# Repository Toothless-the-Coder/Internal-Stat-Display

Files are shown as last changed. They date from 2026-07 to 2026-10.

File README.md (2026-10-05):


# Pi Pico Computer Stats Display

## Why I Built This

I wanted a **physical, always-on display** of my system stats without using up screen space or keeping another app open. Most monitoring tools are digital dashboards on your monitor—I wanted something tangible in my computer. Plus, there's something satisfying about watching real hardware respond to your system's performance in real-time.

## What It Does

This system continuously monitors your Linux computer and displays key performance metrics on three physical LCD screens

### Component Wiring Diagram



## Assenbly instructions
1. Place the screens into their circular cutouts on the front
2. Slide in the plate behind the screens to keep them from falling back
3. Upload the code onto the raspberry pi                                                                 
4. Plug the screens into the raspberry Pi using jumper cables following the wiring diagram just up there 
5. Route the cable from the usb headers through the cutout in the backplate and plug it into the raspberry pi's usb port
6. Screw or glue the raspberry pi's securing plate on (I recommend screws)
7. Screw on the back and top plate and connect it to the usb headers
8. Click it into place in your pc case (Designed specifically for mine so you'll have to edit the external case to make it fit your pc)
9. Enjoy the beautiful displays!

## BOM

| Component | Price | Source | Link |
|---|---|---|---|
| Raspberry Pi Pico | $6 | digikey | https://www.digikey.com/en/products/detail/raspberry-pi/SC0918/16608263 |
| 6mm m2x.4 screws | $0.65 | digikey | https://www.digikey.com/en/products/detail/essentra-components/50M020040G004/11638015 |
| 3x LCD 1602 + I2C backpack | $14.99 each | WaveShare | https://www.waveshare.com/1.28inch-lcd-module.htm |
| Micro USB cable | $8.43 | newegg | https://www.newegg.com/p/27U-00H1-000P4?Item=9SIAERNM1X0850 |
| Digikey Shipping | $8.49 | FedEx Ground | |
| NewEgg Shipping | Free | | |
| WaveShare Shipping | $10.00 | | |
| Print Legion | $5.00 | | |
| **Total** | **~$83.54** | | |






I do not have a hackatime project for this, the connectors aren't jst, they're standard 2.54mm shrouded pin sockets which will connect to the pi via jumper cables, I am planning to have this printed through hack club's print legion, the last reviewer said to include the costs of print legion in the bom, but I was under the impression that print legion was free.

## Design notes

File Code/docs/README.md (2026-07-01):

# Pi Pico Computer Stats Display

> A compact, always-on dashboard for monitoring your Linux system—built with hardware that costs less than a coffee.

## 🎯 Why I Built This

I wanted a **physical, always-on display** of my system stats without using screen real estate or keeping another app open. Most monitoring tools are digital dashboards on your monitor—I wanted something tangible on my desk. Plus, there's something satisfying about watching real hardware respond to your system's performance in real-time.

This project combines:
- **Raspberry Pi Pico** (~$5)—a tiny, powerful microcontroller
- **3 LCD displays**—each showing different stats
- **Your Linux computer**—streaming live data

The result? A **device that sits on your desk and shows your system's heartbeat** in real-time.

## 📊 What It Does

This system continuously monitors your Linux computer and displays key performance metrics on three physical LCD screens:

```
┌─────────────────┐    ┌─────────────────┐    ┌─────────────────┐
│  SCREEN 1       │    │  SCREEN 2       │    │  SCREEN 3       │
│                 │    │                 │    │                 │
│  CPU: 45.2%     │    │  RAM: 62.3%     │    │  GPU: 78%       │
│  Temp: 52.5°C   │    │  Net: 1.5MB/s   │    │  OK             │
└─────────────────┘    └─────────────────┘    └─────────────────┘
```

**Monitored Stats:**
- CPU usage percentage
- RAM usage percentage
- GPU usage percentage
- CPU temperature
- Network speed

All updating in real-time, wirelessly communicating over USB.

## 🔧 How It Fits Together

### The Big Picture

```
┌──────────────────────────────────────────────────────────────┐
│                      YOUR LINUX PC                           │
│                                                              │
│  ┌─────────────────────────────────────────────────────┐   │
│  │ stat_sender.py (Python script)                      │   │
│  │ • Reads CPU, RAM, GPU, Temperature, Network data   │   │
│  │ • Packages it as JSON                              │   │
│  │ • Sends over USB serial connection                 │   │
│  └────────────────────────────┬────────────────────────┘   │
│                               │                             │
│                          USB Port                           │
│                          (Serial)                           │
│                               │                             │
└───────────────────────────────┼─────────────────────────────┘
                                │
                        [USB Cable]
                                │
┌───────────────────────────────┼─────────────────────────────┐
│                               │                             │
│  ┌────────────────────────────▼───────────────────────┐    │
│  │         RASPBERRY PI PICO (Microcontroller)        │    │
│  │                                                    │    │
│  │  • Receives JSON data via USB serial              │    │
│  │  • Decodes and parses stats                       │    │
│  │  • Manages 3 I2C LCD displays in parallel         │    │
│  └────────────────┬──────────────────────────────────┘    │
│                   │                                        │
│        I2C Bus (2 wires: SDA + SCL)                       │
│                   │                                        │
│    ┌──────────────┼──────────────┐                         │
│    │              │              │                         │
│  ┌─┴──┐         ┌─┴──┐         ┌─┴──┐                      │
│  │LCD1│         │LCD2│         │LCD3│                      │
│  │0x27│         │0x26│         │0x25│                      │
│  └────┘         └────┘         └────┘                      │
│                                                            │
└────────────────────────────────────────────────────────────┘
```

### Hardware Connections

#### **I2C Bus (Data Connection)**

All three LCDs connect to the **same I2C bus** on the Pico using just 2 wires:

```
Raspberry Pi Pico        All 3 LCD Displays
─────────────────        ──────────────────

GPIO0 (SDA) ─────┬──────► LCD1 SDA
            │   LCD2 SDA
            │   LCD3 SDA
            └─────────────────────
                 (all connected)

GPIO1 (SCL) ─────┬──────► LCD1 SCL
            │   LCD2 SCL
            │   LCD3 SCL
            └─────────────────────
                 (all connected)

VBUS (5V) ────┬──────► LCD1 VCC
          │   LCD2 VCC
          │   LCD3 VCC
          └─────────────────────

GND ──────┬──────► LCD1 GND
          │   LCD2 GND
          │   LCD3 GND
          └─────────────────────
```

**Why I2C?** It's designed for exactly this—multiple devices on the same bus, each with a unique address. Perfect for daisy-chaining displays.

#### **USB Connection (Power + Data)**

```
Raspberry Pi Pico              Your Linux Computer
─────────────────              ───────────────────

Micro USB Port ════════════════ USB Port
  - Power (5V)
  - Data (RX/TX serial)
```

The USB provides:
- **Power** to run the Pico and LCDs
- **Data** for serial communication (115200 baud)

### Component Wiring Diagram

```
                    Raspberry Pi Pico
                    
                    USB [to computer]
                     ▲
                     │
        ┌────────────┼────────────┐
        │            │            │
      VBUS          GND     GPIO0/GPIO1
        │            │        (SDA/SCL)
        │            │           │
        ├────────────┼───────────┬┤
        │            │           ││
     ┌──┴──┐     ┌───┴──┐   ┌───┴┴──┐
     │     │     │      │   │       │
    LCD1  LCD2  LCD3   GND  Pull-up  (optional)
   0x27  0x26  0x25    All  4.7kΩ   Resistors
     │     │     │      │   │
    VCC   VCC   VCC    GND  
     │     │     │      │
    (All connected in parallel on same 4 wires)
```

## 📦 The Three Screens

Each LCD is independently addressable on the I2C bus:

| Screen | Address | Content | Purpose |
|---|---|---|---|
| **LCD1** | `0x27` | CPU Usage + Temperature | Processor monitoring |
| **LCD2** | `0x26` | RAM Usage + Network Speed | Memory & connectivity |
| **LCD3** | `0x25` | GPU Usage + Status | Graphics performance |

## 🎛️ System Features
- Real-time system stat monitoring (CPU, RAM, GPU, Temperature, Network)
- Display on three separate 16x2 character LCD screens
- USB serial communication from host computer
- JSON-based protocol for easy extension
- Low power consumption (~500mA)
- Auto-detection of connected displays

## 🛒 What You Need

| Component | Price | Source |
|---|---|---|
| Raspberry Pi Pico | $5 | raspberrypi.com |
| 3x LCD 1602 + I2C backpack | $3-5 each | Amazon/AliExpress |
| Micro USB cable | $2-5 | Any electronics store |
| Breadboard & jumper wires | $5-10 | Electronics kit |
| **Total** | **~$30-40** | Budget-friendly! |

### Raspberry Pi Pico Specs
- **Microcontroller:** RP2040
- **RAM:** 264KB
- **Flash:** 2MB
- **I2C Support:** 2 I2C buses
- **UART Support:** 2 serial ports
- **Size:** 21x51mm (tiny!)

### LCD Displays
- **Type:** 1602 (16 characters × 2 rows)
- **Connection:** I2C via PCF8574 backpack
- **Power:** 5V
- **Current:** ~80-150mA per display (with backlight)

## 🏗️ Software Architecture

### On the Pico (MicroPython)

```
main.py ─────────────────────────────────────
    │
    ├─► config.py ◄─ [Configuration: pins, addresses, update rate]
    │
    ├─► serial_handler.py ◄─ [Receives JSON from Linux]
    │        │
    │        └─► Parses incoming stats
    │
    ├─► display_manager.py ◄─ [Manages 3 LCD screens]
    │        │
    │        └─► Updates stats on displays
    │
    └─► lcd_i2c.py ◄─ [I2C LCD driver]
             │
             └─► Controls each display
```

**Key Files:**
- `main.py` — Runs the main loop
- `config.py` — I2C pins, LCD addresses, update speed
- `serial_handler.py` — Reads JSON from USB
- `display_manager.py` — Logic for what shows on each screen
- `lcd_i2c.py` — Low-level LCD communication

### On Your Linux Computer (Python 3)

```
stat_sender.py ────────────────────────────────
    │
    ├─► Read system stats (psutil library)
    │    ├─ CPU usage
    │    ├─ RAM usage
    │    ├─ GPU usage
    │    ├─ Temperature
    │    └─ Network speed
    │
    ├─► Format as JSON
    │
    └─► Send via USB serial
             │
             └─► To Pico
```

**Key File:**
- `stat_sender.py` — Gathers stats and sends to Pico

## ⚡ Quick Start (15 Minutes)

**Start here:** See [QUICKSTART.md](../QUICKSTART.md)

For detailed setup:
1. [Wiring & Hardware Setup](../docs/HARDWARE.md)
2. [Pico Firmware Installation](../QUICKSTART.md)
3. [Linux Sender Setup](../linux_sender/SETUP.md)

## 🚀 Running It

### Start the Linux Sender

```bash
cd linux_sender
python3 stat_sender.py
```

**Options:**
```bash
python3 stat_sender.py --port /dev/ttyACM0  # Specify port
python3 stat_sender.py --interval 2.0       # Update every 2 seconds
python3 stat_sender.py --baud 115200        # Custom baud rate
```

**That's it!** Stats should start appearing on your displays within seconds.

### Run as a Background Service

To have it start automatically on boot:

```bash
# See linux_sender/SETUP.md for systemd service installation
```

## 🖥️ What You'll See

The three LCD displays show:

```
LCD 1 (0x27)              LCD 2 (0x26)              LCD 3 (0x25)
┌──────────────────┐      ┌──────────────────┐      ┌──────────────────┐
│ CPU: 45.2%       │      │ RAM: 62.3%       │      │ GPU: 78%         │
│ Temp: 52.5C      │      │ Net: 1.5MB/s     │      │ Stat Display OK  │
└──────────────────┘      └──────────────────┘      └──────────────────┘
```

Each display updates **1x per second** (configurable).

## 🔧 Troubleshooting

| Problem | Solution |
|---|---|
| **No displays showing** | Check I2C wiring: SDA (GPIO0), SCL (GPIO1), power, ground |
| **Only some displays work** | Run I2C scan to find addresses, update `config.py` |
| **Serial connection fails** | Check port: `ls /dev/ttyACM*` or use `--port` option |
| **Stats not updating** | Verify `stat_sender.py` is running |
| **Garbled text on displays** | Ensure 5V power to LCDs, check wiring |

**For detailed troubleshooting:** See [HARDWARE.md](../docs/HARDWARE.md)

## Performance Notes

- I2C clock: 400kHz (standard)
- Serial baud: 115200
- Update frequency: 1 second (adjustable)
- Pico CPU usage: <5% typical

## 💬 How Devices Communicate

The Pico and Linux computer exchange information in **JSON format** over USB serial.

### Message Format (Linux → Pico)

```json
{
  "cpu": 45.2,
  "ram": 62.3,
  "gpu": 78,
  "temp": 52.5,
  "network": "1.5MB/s"
}
```

Each message is one line, sent **1x per second**.

**For the full protocol spec:** See [PROTOCOL.md](../docs/PROTOCOL.md)

## ⚙️ Performance Specs

- **I2C Speed:** 400kHz (standard)
- **Serial Baud:** 115200
- **Update Frequency:** 1 second (adjustable)
- **Pico CPU Usage:** <5%
- **Power Consumption:** 400-600mA total

## 📚 Documentation

- **[QUICKSTART.md](../QUICKSTART.md)** — Get running in 15 minutes
- **[HARDWARE.md](../docs/HARDWARE.md)** — Detailed wiring and troubleshooting
- **[PROTOCOL.md](../docs/PROTOCOL.md)** — Communication format and extending
- **[SETUP.md](../linux_sender/SETUP.md)** — Linux sender installation

## 🛠️ Customization

### Change Update Frequency
Edit `pico_firmware/config.py`:
```python
UPDATE_INTERVAL = 500  # Update every 500ms instead of 1000ms
```

### Adjust What's Displayed
Edit `pico_firmware/display_manager.py`:
```python
def _display_screen_0(self, lcd):
    # Customize Screen 1 here
    cpu_str = f"CPU: {self.stats['cpu']}%"
    custom_str = f"Your stat here"
    lcd.write_line(0, cpu_str)
    lcd.write_line(1, custom_str)
```

### Add New Statistics
1. Update Linux sender to collect the stat
2. Add the field to the JSON message
3. Update Pico's `display_manager.py` to show it

See [PROTOCOL.md](../docs/PROTOCOL.md) for a detailed example.

## 🚀 Future Ideas

- [ ] OLED display support for better visuals
- [ ] Graph mode (bar graphs on LCD)
- [ ] SD card logging
- [ ] Pi Pico W (wireless Ethernet instead of USB)
- [ ] Custom character support for better icons
- [ ] Multi-computer monitoring

## 📝 License

Open source — modify and share freely!

## 🤝 Support

1. **Can't get it working?** Start with [QUICKSTART.md](../QUICKSTART.md)
2. **Hardware issues?** Check [HARDWARE.md](../docs/HARDWARE.md)
3. **Need more info?** See full documentation in `/docs`

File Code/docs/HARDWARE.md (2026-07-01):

# Hardware Setup Guide

## Pinout Reference

### Raspberry Pi Pico

```
        USB
       ╔═══╗
     1 ║o o║ 40
    20 ╚═══╝ 21

GPIO Pins (numbers are GPIO numbers):
Top Row (L to R):    1(GP0), 2(GP1), 4(GP2), 5(GP3), 7(GP4), 8(GP5),
                     10(GP6), 11(GP7), 13(GP8), 14(GP9), 16(GP10), 17(GP11),
                     19(GP12), 20(GP13), 22(GP14), 24(GP15), 25(GP16), 26(GP17),
                     27(GP18), 28(GP19), 30(GP20), 31(GP21), 32(GP22)

Bottom Row (L to R):  GND, GP23, GND, GND, GND, VSYS, GND, 3V3-OUT, 3V3-EN
```

### I2C LCD 1602 Pinout (with PCF8574 Backpack)

```
Pin 1: VSS (GND)
Pin 2: VDD (5V)
Pin 3: V0 (Contrast) - Connected to backpack
Pin 4: RS (Register Select) - PCF8574 Pin 0
Pin 5: RW (Read/Write) - PCF8574 Pin 1 (GND on backpack)
Pin 6: EN (Enable) - PCF8574 Pin 2
Pin 7-10: D4-D7 (Data pins) - PCF8574 Pins 4-7
Pin 11-14: D0-D3 (not used in 4-bit mode)
Pin 15: A (Backlight +) - PCF8574 Pin 3 through resistor
Pin 16: K (Backlight -) - GND
```

## Wiring Diagram

### Single I2C LCD to Pico

```
LCD I2C Backpack          Raspberry Pi Pico
─────────────────         ──────────────────
VCC (5V)   ────────────── VBUS (Pin 40)
GND        ────────────── GND (Pin 38, 43)
SDA        ────────────── GPIO0 (Pin 1)
SCL        ────────────── GPIO1 (Pin 2)
```

### Three I2C LCDs to Pico (Parallel I2C Bus)

```
                     ┌─────────┐
                     │ Pico    │
                     │ GPIO0   │
                     │ (SDA)   │
                     │ GPIO1   │
                     │ (SCL)   │
                     │ VBUS    │
                     │ GND     │
                     └────┬────┘
                          │
        ┌─────────────────┼─────────────────┐
        │                 │                 │
    ┌───┴────┐        ┌───┴────┐       ┌───┴────┐
    │LCD1    │        │LCD2    │       │LCD3    │
    │0x27    │        │0x26    │       │0x25    │
    └────────┘        └────────┘       └────────┘
```

All three LCDs share the same SDA and SCL lines (I2C is a shared bus).
Each LCD has a different I2C address (set via A0, A1, A2 pins on backpack).

## I2C Address Selection

PCF8574 I2C addresses are determined by A0, A1, A2 pins:

| A2 | A1 | A0 | Address |
|----|----|----|---|
| 0  | 0  | 0  | 0x20 |
| 0  | 0  | 1  | 0x21 |
| 0  | 1  | 0  | 0x22 |
| 0  | 1  | 1  | 0x23 |
| 1  | 0  | 0  | 0x24 |
| 1  | 0  | 1  | 0x25 |
| 1  | 1  | 0  | 0x26 |
| 1  | 1  | 1  | 0x27 |

Most modules default to 0x27 (all pins pulled high).

## Component List

### Essential
- 1x Raspberry Pi Pico (~$5)
- 3x LCD 1602 displays with I2C backpack (~$10-15 each)
- 1x Micro USB cable (for power/data)
- 1x Breadboard (for prototyping)
- Jumper wires (22 AWG)

### Recommended
- Pull-up resistors: 4.7kΩ (2x, for SDA/SCL lines)
- Small resistor: 330Ω (for LCD backlight, already included on most backpacks)
- Pi Pico debug probe (optional, for advanced debugging)

## Assembly Steps

### 1. Connect I2C Bus
Solder or connect with breadboard:
- Connect all LCD SDA pins → Pico GPIO0 (Pin 1)
- Connect all LCD SCL pins → Pico GPIO1 (Pin 2)
- Connect all LCD GND → Pico GND
- Connect all LCD VCC → Pico VBUS (5V)

### 2. Add Pull-up Resistors (if needed)
If LCDs aren't responding:
- 4.7kΩ resistor from SDA → VBUS
- 4.7kΩ resistor from SCL → VBUS

### 3. Verify I2C Addresses
Set different addresses on each LCD by connecting/leaving A0, A1, A2 pins:
- Open each display and set pins as needed
- Or program via I2C address selection

### 4. USB Connection
- Connect Pico micro USB port to Linux computer

## Power Considerations

### Power Budget
- Pico: ~120mA typical
- Each LCD (with backlight): ~80-150mA
- Total: ~500-600mA

**Note:** Most USB ports provide 500mA, so you may need a powered hub or additional power supply for all displays at full brightness.

### Reducing Power
- Reduce LCD backlight brightness (PWM on backlight pin)
- Reduce I2C clock speed (affects power consumption slightly)
- Reduce stat update frequency

## Testing the Wiring

### Test 1: Scan I2C Bus
```python
import machine
i2c = machine.I2C(0, scl=machine.Pin(1), sda=machine.Pin(0), freq=400000)
devices = i2c.scan()
print(f"Found {len(devices)} devices: {[f'0x{d:02x}' for d in devices]}")
# Should output: Found 3 devices: ['0x27', '0x26', '0x25']
```

### Test 2: Write to LCD
```python
from lcd_i2c import LCD_I2C
i2c = machine.I2C(0, scl=machine.Pin(1), sda=machine.Pin(0))
lcd = LCD_I2C(i2c, 0x27, 2, 16)
lcd.write_line(0, "Test Display")
lcd.write_line(1, "Screen 1")
```

### Test 3: Check USB Serial
```bash
# Linux
sudo dmesg | tail
# Look for "CDC ACM device" or similar
ls /dev/ttyACM*
```

## Troubleshooting Hardware

### LCDs Not Responding
1. Check power: Measure 5V on LCD VCC pin
2. Check I2C communication: Use logic analyzer or oscilloscope
3. Verify pull-up resistors if bus fails at distances > 1m

### One LCD Missing from Scan
1. Check physical connection
2. Verify A0/A1/A2 pins set correctly
3. Try swapping with known-working LCD
4. Reset LCD with power cycle

### Intermittent Display Glitches
1. Reduce I2C clock speed in code (from 400kHz to 100kHz)
2. Add 0.1µF capacitors near LCD power pins
3. Check for ground loops or long wire runs

### USB Connection Not Working
1. Try different USB port on computer
2. Try different USB cable (some are power-only)
3. Check dmesg for connection errors
4. Press BOOTSEL + Power to reset Pico

## Performance Tips

- **I2C Speed**: 400kHz is standard and reliable
- **Cable Length**: Keep I2C cables <1m for 400kHz
- **Power Supply**: Use regulated 5V, not USB hub's voltage
- **Grounding**: Good ground connections are critical for I2C reliability

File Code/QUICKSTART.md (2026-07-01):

# Quick Start Guide

Get your Pi Pico stat display running in 15 minutes.

## Prerequisites

- Raspberry Pi Pico (flashed with MicroPython)
- 3x LCD 1602 displays with I2C backpack
- Linux computer
- USB cable for Pico
- Python 3.7+ on Linux

## Step 1: Flash MicroPython to Pi Pico (5 min)

1. Download MicroPython: https://micropython.org/download/rp2-pico/
2. Hold BOOTSEL button on Pico
3. Connect USB to computer (Pico still held)
4. Release BOOTSEL
5. Copy downloaded `.uf2` file to `RPI-RP2` drive
6. Pico reboots automatically

## Step 2: Verify I2C Addresses (2 min)

Use Thonny IDE to run this code on Pico:

```python
import machine
i2c = machine.I2C(0, scl=machine.Pin(1), sda=machine.Pin(0))
print("I2C addresses found:", [hex(addr) for addr in i2c.scan()])
```

Should output something like: `['0x27', '0x26', '0x25']`

If not all three show up:
- Check wiring
- Verify LCD power connections
- See [HARDWARE.md](HARDWARE.md) troubleshooting

## Step 3: Upload Pico Firmware (3 min)

In Thonny IDE:
1. File → Open → Select each Python file from `pico_firmware/`
2. Save each to Pico (right-click file → Save to device)
3. Upload in this order:
   - `config.py`
   - `lcd_i2c.py`
   - `serial_handler.py`
   - `display_manager.py`
   - `main.py`

Pico should start running automatically after `main.py` is uploaded.

## Step 4: Setup Linux Sender (3 min)

```bash
cd linux_sender
pip install -r requirements.txt
python3 stat_sender.py
```

That's it! You should see stats updating on the displays.

## Troubleshooting

### No stats appearing on display?

1. **Check serial connection:**
   ```bash
   ls /dev/ttyACM*
   ```

2. **Check I2C connection:**
   - Run I2C scan in Thonny (Step 2)
   - All three LCDs should appear

3. **Manual port specification:**
   ```bash
   python3 stat_sender.py --port /dev/ttyACM0
   ```

4. **Check Pico output:**
   - Open Thonny serial monitor
   - Should see connection messages
   - Watch for errors

### One or more LCDs not showing data?

- Check I2C address (run scan, update `config.py`)
- Verify all are connected to same I2C bus
- Check power to each LCD

### Stats not updating?

- Verify stat_sender.py is running: `ps aux | grep stat_sender`
- Check for errors in Linux terminal
- Restart both Pico and stat_sender

## What's Next?

- **Customize stats:** Edit `display_manager.py` to show different info
- **Change refresh rate:** Edit `UPDATE_INTERVAL` in `config.py`
- **Add new metrics:** See [PROTOCOL.md](../docs/PROTOCOL.md) for extending
- **Run as service:** See [SETUP.md](SETUP.md) for systemd integration

## Important Files

| File | Purpose |
|---|---|
| `pico_firmware/main.py` | Pico entry point |
| `pico_firmware/config.py` | I2C addresses, pins, update rate |
| `linux_sender/stat_sender.py` | Sends system stats to Pico |
| `docs/README.md` | Full documentation |
| `docs/HARDWARE.md` | Wiring diagrams |
| `docs/PROTOCOL.md` | Communication format |

## Display Layout

**LCD 1 (Screen 1):**
```
CPU: 45.2%
Temp: 52.5C
```

**LCD 2 (Screen 2):**
```
RAM: 62.3%
Net: 1.5MB/s
```

**LCD 3 (Screen 3):**
```
GPU: 78%
Stat Display OK
```

## Performance

- CPU usage (Pico): <5%
- CPU usage (Linux): <2%
- Update latency: <100ms
- Power consumption: ~400-600mA

## Support

For detailed information:
- Wiring issues → See `docs/HARDWARE.md`
- Communication problems → See `docs/PROTOCOL.md`
- Installation help → See `linux_sender/SETUP.md`
- General info → See `docs/README.md`

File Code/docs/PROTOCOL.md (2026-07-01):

# Communication Protocol

## Overview

The Pi Pico and Linux computer communicate via USB serial using JSON messages. Each message is one line of JSON terminated with a newline (`\n`).

## Baud Rate & Serial Settings
- **Baud Rate**: 115200
- **Data Bits**: 8
- **Parity**: None
- **Stop Bits**: 1
- **Flow Control**: None

## Message Format

All messages are UTF-8 encoded JSON strings, one per line.

### Host → Pico: Statistics Update

**Message Type**: `stats`

```json
{
  "cpu": 45.2,
  "ram": 62.3,
  "gpu": 78,
  "temp": 52.5,
  "network": "1.5MB/s"
}
```

**Fields:**
| Field | Type | Range | Description |
|---|---|---|---|
| `cpu` | float | 0-100 | CPU usage percentage |
| `ram` | float | 0-100 | RAM usage percentage |
| `gpu` | float | 0-100 | GPU usage percentage (0 if unavailable) |
| `temp` | float | -50-120 | CPU temperature in Celsius |
| `network` | string | - | Network speed (e.g., "1.5MB/s", "250KB/s") |

**Frequency**: Recommended 1-2 times per second for smooth display updates

### Pico → Host: Status Acknowledgment (Optional)

**Message Type**: `status`

```json
{"status": "ok"}
```

Sent by Pico after successfully parsing a stats message (optional feature, not implemented by default).

## Protocol Examples

### Valid Statistics Messages

```json
{"cpu": 0, "ram": 0, "gpu": 0, "temp": 20, "network": "0KB/s"}

{"cpu": 100, "ram": 95.5, "gpu": 87.2, "temp": 85.3, "network": "500MB/s"}

{"cpu": 45.2, "ram": 62.3, "gpu": 78, "temp": 52.5, "network": "1.5MB/s"}
```

### Invalid Messages (Will Be Ignored)

```json
{"cpu": "high", "ram": 62}   // Invalid: cpu should be number

{cpu: 45.2, ram: 62.3}       // Invalid: not valid JSON (missing quotes)

cpu: 45.2\nram: 62.3         // Invalid: not JSON format
```

## Serial Communication Flow

```
Linux Computer                          Raspberry Pi Pico
────────────────                        ───────────────

stat_sender.py
    │
    ├─ Read system stats
    │
    ├─ Format JSON
    │
    └─ Send via USB serial
                                        ├─ Receive via UART
                                        │
                                        ├─ Parse JSON
                                        │
                                        ├─ Update display
                                        │
                                        └─ Optionally send ACK
    
    Repeat at configured interval (default: 1 second)
```

## Error Handling

### Pico Behavior on Invalid Data

1. **Invalid JSON**: Message is ignored, error printed to REPL
2. **Missing Fields**: Preserved stats retain previous values
3. **Serial Overflow**: Buffer limited to 256 characters, older data discarded
4. **Timeout**: No timeout - Pico waits indefinitely

### Host Behavior

1. **Connection Lost**: stat_sender.py exits with error
2. **Port Error**: Retries every 5 seconds (configurable)
3. **System Stats Error**: Uses last valid stats or shows "N/A"

## Extending the Protocol

To add new statistics:

### 1. Update Linux Sender

In `linux_sender/stat_sender.py`:

```python
def get_system_stats(self):
    stats = {
        'cpu': psutil.cpu_percent(interval=0.5),
        'ram': psutil.virtual_memory().percent,
        'gpu': self._get_gpu_usage(),
        'temp': self._get_cpu_temp(),
        'network': self._get_network_speed(),
        'disk': self._get_disk_usage(),  # NEW FIELD
    }
    return stats

def _get_disk_usage(self):
    """Get disk usage percentage"""
    disk = psutil.disk_usage('/')
    return disk.percent
```

### 2. Update Pico Firmware

In `pico_firmware/display_manager.py`:

```python
def __init__(self, lcds):
    self.stats = {
        'cpu': 'N/A',
        'ram': 'N/A',
        'gpu': 'N/A',
        'temp': 'N/A',
        'network': 'N/A',
        'disk': 'N/A',  # NEW FIELD
    }

def _display_screen_new(self, lcd):
    """Display Screen N: Disk usage"""
    disk_str = f"Disk: {self._format_stat(self.stats['disk'])}%"[:16]
    other_str = "Storage Info"[:16]
    
    lcd.clear()
    lcd.write_line(0, disk_str)
    lcd.write_line(1, other_str)
```

### 3. Update Configuration

In `pico_firmware/config.py`:

```python
# Add new display mode
STAT_ROTATION = {
    0: ['cpu', 'temp'],
    1: ['ram', 'network'],
    2: ['gpu', 'disk'],  # NEW
}
```

## Debugging

### Monitor Serial Communication

#### Using minicom (Linux)
```bash
minicom -D /dev/ttyACM0 -b 115200
```

#### Using screen (Linux)
```bash
screen /dev/ttyACM0 115200
```

#### Using pyserial (Python)
```python
import serial
ser = serial.Serial('/dev/ttyACM0', 115200)
while True:
    line = ser.readline().decode('utf-8')
    print(f"Received: {line}")
```

### Enable Debug Output

Add to `main.py`:

```python
DEBUG = True

if DEBUG:
    print(f"Received data: {data}")
    print(f"Stats: {display_manager.stats}")
```

### Test Message Send

```python
# In Thonny REPL on Pico
from serial_handler import SerialHandler
ser = SerialHandler()
ser.write_data({"cpu": 50, "ram": 60, "gpu": 70, "temp": 45, "network": "100KB/s"})
```

## Performance Considerations

- **Message Size**: ~80-100 bytes typical (well within serial buffer)
- **Throughput**: 1 message/second = ~1KB/minute (minimal bandwidth)
- **Latency**: <10ms typical (USB serial + Pico processing)
- **CPU Usage**: <1% on Pico, <2% on Linux host

## Security Notes

- No authentication/encryption (local USB connection assumed safe)
- No buffer overflow protection (length limits in place)
- No rate limiting (could DOS with rapid messages, but single host expected)
- If extended for network use, consider:
  - Message signing
  - Rate limiting
  - Data validation schemas

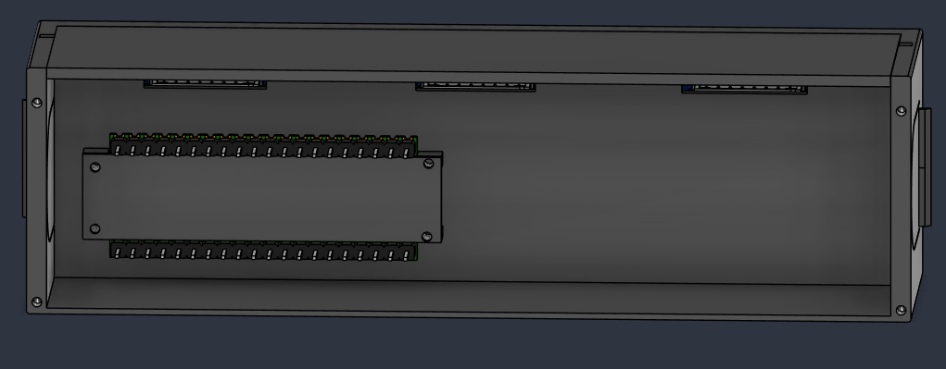
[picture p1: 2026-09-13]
Images/Screenshot 2026-09-10 160519.png

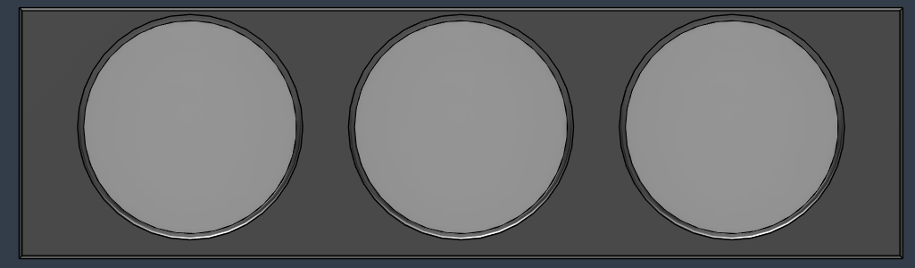
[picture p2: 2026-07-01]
Images/Screenshot 2026-06-14 211706.png

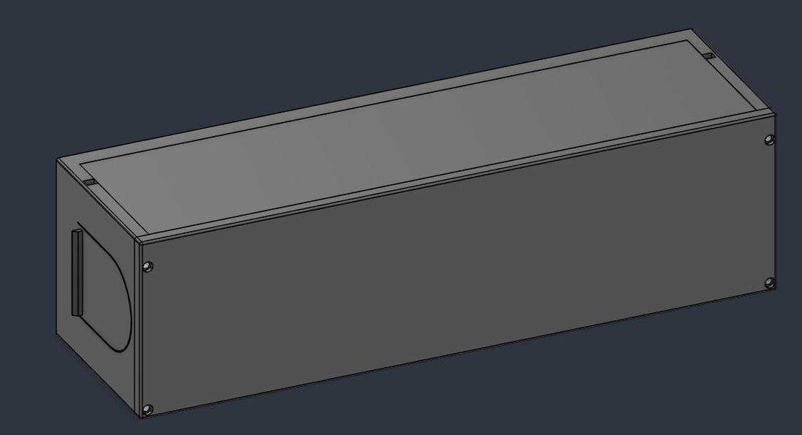
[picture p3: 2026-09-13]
Images/Screenshot 2026-09-10 160801.png

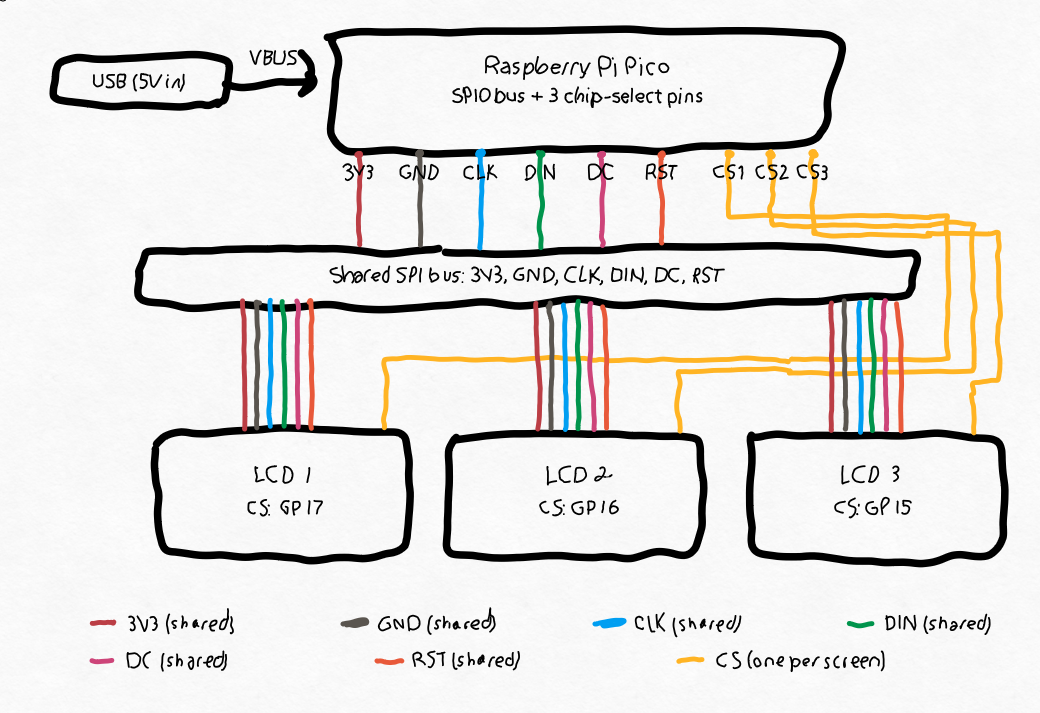
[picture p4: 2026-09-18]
Images/image.png

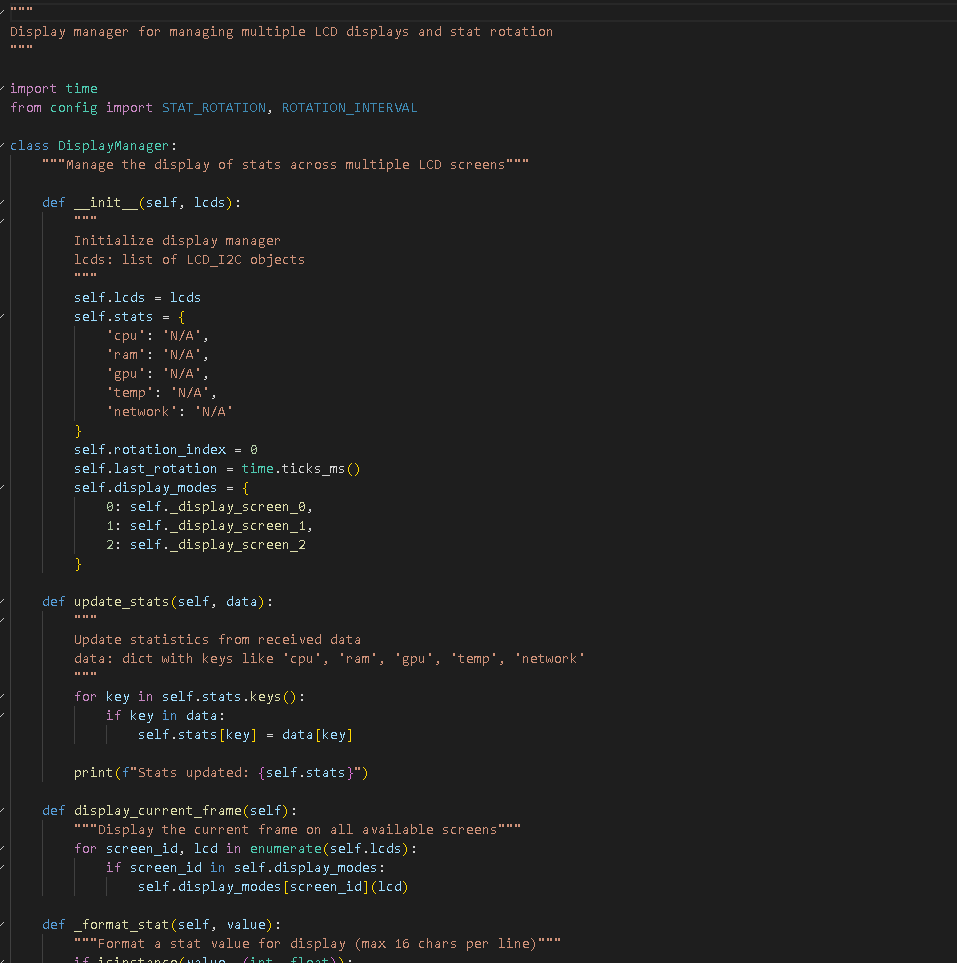
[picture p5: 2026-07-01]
Images/Screenshot 2026-06-30 104208.png

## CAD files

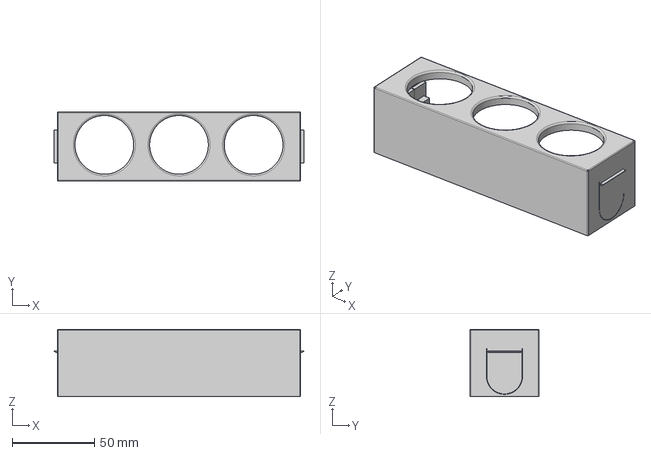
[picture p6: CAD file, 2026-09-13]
CAD/Main Body.step
152.0 x 42.0 x 41.0 mm

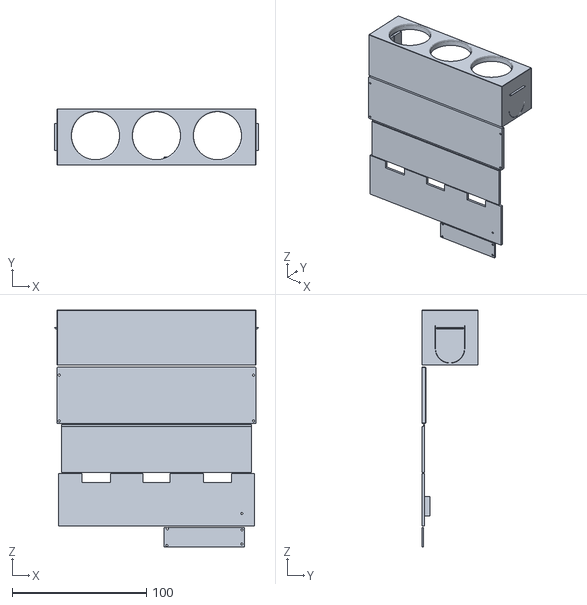
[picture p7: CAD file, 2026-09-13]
CAD/Case.stl
152.0 x 42.0 x 176.3

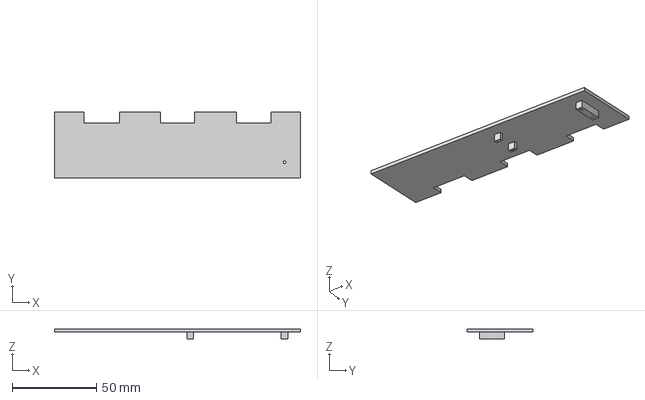
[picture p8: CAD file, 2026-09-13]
CAD/Screen Plate.step
145.8 x 39.1 x 6.13 mm

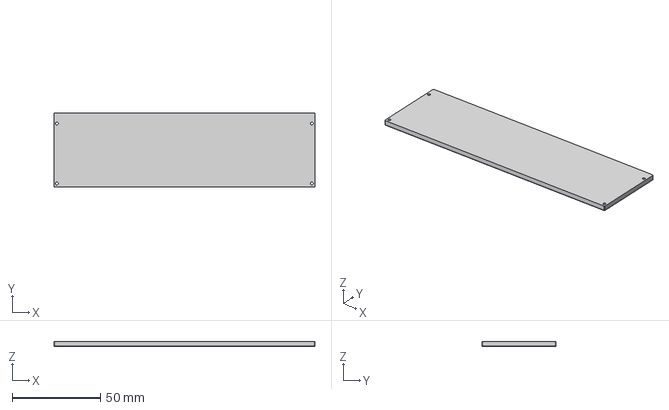
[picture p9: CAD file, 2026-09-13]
CAD/Back Plate.step
148.0 x 42.0 x 3.00 mm

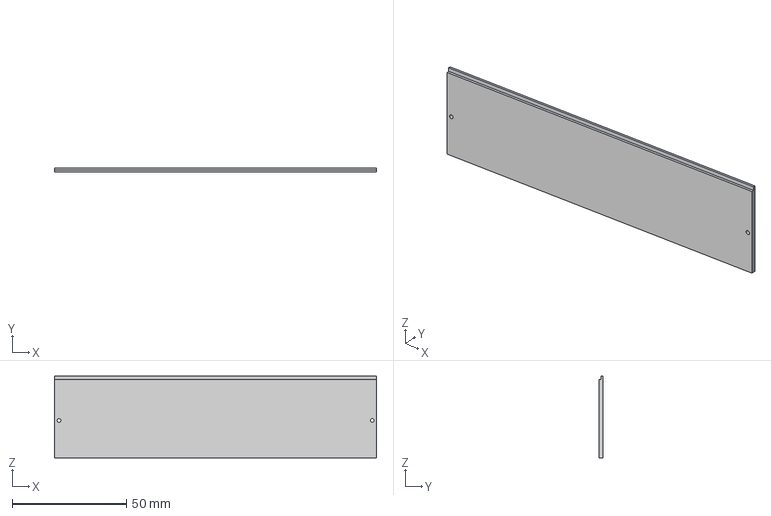
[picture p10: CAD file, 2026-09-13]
CAD/Top Plate.step
141.2 x 1.86 x 35.9 mm

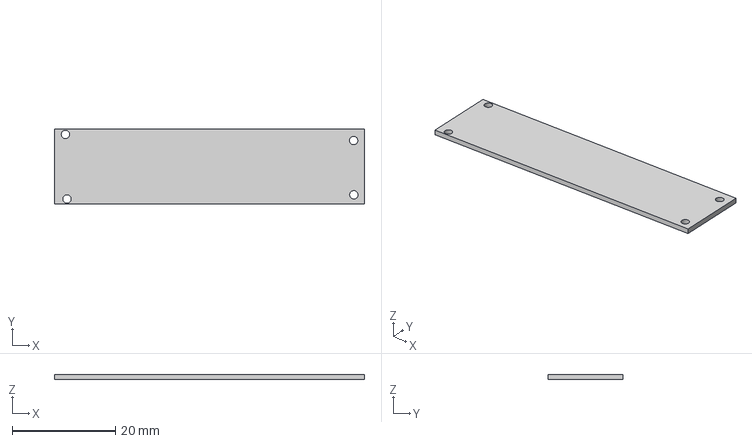
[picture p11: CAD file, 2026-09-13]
CAD/Rasp Pi Plate.step
60.0 x 14.6 x 1.00 mm

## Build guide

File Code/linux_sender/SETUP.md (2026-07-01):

# Pi Pico Stat Display - Linux Sender Setup

## Quick Start

### 1. Install Python Dependencies

```bash
pip install -r requirements.txt
```

### 2. Find Your Pi Pico's Serial Port

```bash
ls /dev/ttyACM* 
# or
dmesg | grep USB
```

### 3. Run the Sender

```bash
# Auto-detect Pi Pico
python3 stat_sender.py

# Or specify port explicitly
python3 stat_sender.py --port /dev/ttyACM0

# Custom update interval (e.g., 2 seconds)
python3 stat_sender.py --interval 2.0
```

### 4. Run as a Service (Optional)

Create a systemd service file:

```bash
sudo nano /etc/systemd/system/pico-stat-sender.service
```

Add the following (adjust paths as needed):

```ini
[Unit]
Description=Pi Pico Stat Sender
After=network.target

[Service]
Type=simple
User=pi
WorkingDirectory=/home/pi/pico-stat-sender
ExecStart=/usr/bin/python3 stat_sender.py
Restart=always
RestartSec=5

[Install]
WantedBy=multi-user.target
```

Enable and start:

```bash
sudo systemctl daemon-reload
sudo systemctl enable pico-stat-sender
sudo systemctl start pico-stat-sender
```

Check status:

```bash
sudo systemctl status pico-stat-sender
```

## Command Line Options

- `--port PORT`: Specify serial port manually (e.g., `/dev/ttyACM0`)
- `--baud RATE`: Set baud rate (default: 115200)
- `--interval SECONDS`: Update interval (default: 1.0)

## Troubleshooting

### No Pi Pico Found
- Check the USB cable connection
- Verify the device appears with `lsusb`
- May need to install CH340 drivers: `sudo apt install ch340-dkms`

### Permission Denied
```bash
sudo usermod -a -G dialout $USER
# Then log out and log back in
```

### Serial Port Not Found
- List all ports: `sudo python3 -c "import serial.tools.list_ports; print([p for p in serial.tools.list_ports.comports()])"`
- Try different ports manually with `--port` option

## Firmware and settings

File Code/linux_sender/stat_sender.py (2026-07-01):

#!/usr/bin/env python3
"""
Linux Stat Sender for Raspberry Pi Pico Display
Reads system statistics and sends them via serial to the Pi Pico
"""

import serial
import serial.tools.list_ports
import psutil
import json
import time
import sys
import os
import signal

class StatSender:
    """Send system statistics via serial to Pi Pico"""
    
    def __init__(self, port=None, baud=115200):
        self.baud = baud
        self.ser = None
        self.running = True
        
        # Register signal handler for graceful shutdown
        signal.signal(signal.SIGINT, self._signal_handler)
        signal.signal(signal.SIGTERM, self._signal_handler)
        
        # Connect to serial port
        self.connect(port)
    
    def _signal_handler(self, sig, frame):
        """Handle termination signals"""
        print("\nShutting down...")
        self.running = False
        if self.ser and self.ser.is_open:
            self.ser.close()
        sys.exit(0)
    
    def find_pico_port(self):
        """
        Attempt to find the Pi Pico's serial port
        Returns port name or None
        """
        ports = serial.tools.list_ports.comports()
        
        for port in ports:
            # Check for common Pi Pico identifiers
            if 'Pico' in port.description or 'CH340' in port.description or \
               'USB' in port.description or 'ttyACM' in port.device or \
               'COM' in port.device:
                return port.device
        
        return None
    
    def connect(self, port=None):
        """Connect to the serial port"""
        try:
            # Auto-detect port if not specified
            if port is None:
                port = self.find_pico_port()
                if port:
                    print(f"Found Pi Pico on port: {port}")
                else:
                    print("No Pi Pico found. Available ports:")
                    ports = serial.tools.list_ports.comports()
                    for p in ports:
                        print(f"  {p.device}: {p.description}")
                    raise Exception("Could not find Pi Pico")
            
            self.ser = serial.Serial(port, self.baud, timeout=1)
            print(f"Connected to {port} at {self.baud} baud")
            time.sleep(2)  # Wait for Pi Pico to reset
        except Exception as e:
            print(f"Error connecting to serial port: {e}")
            raise
    
    def get_system_stats(self):
        """Collect system statistics"""
        try:
            # CPU usage
            cpu_percent = psutil.cpu_percent(interval=0.5)
            
            # RAM usage
            ram = psutil.virtual_memory()
            ram_percent = ram.percent
            
            # GPU usage (Linux)
            gpu_percent = self._get_gpu_usage()
            
            # CPU temperature (if available)
            temp = self._get_cpu_temp()
            
            # Network speed
            net_speed = self._get_network_speed()
            
            return {
                'cpu': cpu_percent,
                'ram': ram_percent,
                'gpu': gpu_percent,
                'temp': temp,
                'network': net_speed
            }
        except Exception as e:
            print(f"Error collecting stats: {e}")
            return None
    
    def _get_cpu_temp(self):
        """Get CPU temperature from /sys/class/thermal/thermal_zone0/temp"""
        try:
            with open('/sys/class/thermal/thermal_zone0/temp', 'r') as f:
                temp_millidegrees = int(f.read().strip())
                return temp_millidegrees / 1000.0
        except:
            return 0
    
    def _get_gpu_usage(self):
        """Get GPU usage (placeholder - varies by GPU)"""
        try:
            # This is a placeholder - actual implementation depends on GPU type
            # For NVIDIA, you could use nvidia-smi
            # For Intel/AMD, other tools are needed
            
            # Try to read from /proc/acpi/battery if on ARM
            try:
                import os
                if os.path.exists('/sys/class/thermal/'):
                    # On Raspberry Pi, we might not have GPU usage info
                    return 0
            except:
                pass
            
            return 0
        except:
            return 0
    
    def _get_network_speed(self):
        """Get network speed in KB/s"""
        try:
            net_io_1 = psutil.net_io_counters()
            time.sleep(1)
            net_io_2 = psutil.net_io_counters()
            
            bytes_sent = net_io_2.bytes_sent - net_io_1.bytes_sent
            bytes_recv = net_io_2.bytes_recv - net_io_1.bytes_recv
            
            total_kb = (bytes_sent + bytes_recv) / 1024
            return f"{total_kb:.1f}KB"
        except:
            return "0KB"
    
    def send_stats(self, stats):
        """Send statistics via serial"""
        try:
            if self.ser and self.ser.is_open:
                json_data = json.dumps(stats) + '\n'
                self.ser.write(json_data.encode('utf-8'))
                return True
        except Exception as e:
            print(f"Error sending stats: {e}")
        return False
    
    def run(self, interval=1):
        """
        Main loop - continuously collect and send stats
        interval: time in seconds between updates
        """
        print("Starting stat collection (press Ctrl+C to stop)...")
        print("-" * 50)
        
        while self.running:
            try:
                stats = self.get_system_stats()
                if stats:
                    if self.send_stats(stats):
                        # Display stats locally
                        print(f"\rCPU: {stats['cpu']:5.1f}% | "
                              f"RAM: {stats['ram']:5.1f}% | "
                              f"GPU: {stats['gpu']:5.1f}% | "
                              f"Temp: {stats['temp']:5.1f}C | "
                              f"Net: {stats['network']}", end="", flush=True)
                    else:
                        print("Warning: Failed to send stats")
                
                time.sleep(interval)
            except KeyboardInterrupt:
                self.running = False
            except Exception as e:
                print(f"Error in main loop: {e}")
                time.sleep(1)

def main():
    import argparse
    
    parser = argparse.ArgumentParser(
        description='Send Linux system stats to Raspberry Pi Pico via serial'
    )
    parser.add_argument('--port', help='Serial port (e.g., /dev/ttyACM0, COM3)')
    parser.add_argument('--baud', type=int, default=115200, help='Baud rate (default: 115200)')
    parser.add_argument('--interval', type=float, default=1.0, help='Update interval in seconds (default: 1.0)')
    
    args = parser.parse_args()
    
    try:
        sender = StatSender(port=args.port, baud=args.baud)
        sender.run(interval=args.interval)
    except KeyboardInterrupt:
        print("\nExiting...")
    except Exception as e:
        print(f"Fatal error: {e}")
        sys.exit(1)

if __name__ == '__main__':
    main()

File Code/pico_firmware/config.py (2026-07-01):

"""
Configuration for the Pi Pico Stat Display
Modify these settings based on your hardware setup
"""

# I2C Configuration
I2C_PORT = 0  # I2C0 (GPIO0/GP1) or I2C1 (GPIO2/3)
I2C_SDA = 0   # GPIO0 for I2C0, or GPIO2 for I2C1
I2C_SCL = 1   # GPIO1 for I2C0, or GPIO3 for I2C1

# LCD I2C Addresses (default for common I2C LCD modules)
# Adjust these based on your specific modules
LCD_ADDRESSES = [0x27, 0x26, 0x25]  # 3 LCD displays

# Display settings
UPDATE_INTERVAL = 1000  # Update display every 1000ms (1 second)
ROTATION_INTERVAL = 5000  # Rotate displayed stats every 5 seconds

# Serial Configuration
SERIAL_BAUD = 115200
SERIAL_TIMEOUT = 100  # milliseconds

# Stats display rotation (which stats show on each screen)
STAT_ROTATION = {
    0: ['cpu', 'temp'],      # Screen 1: CPU and Temperature
    1: ['ram', 'network'],   # Screen 2: RAM and Network
    2: ['gpu', 'info']       # Screen 3: GPU and System Info
}

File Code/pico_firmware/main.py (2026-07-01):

"""
Raspberry Pi Pico - Computer Stats Display
Main entry point for the MicroPython firmware
"""

import machine
import time
from config import *
from lcd_i2c import LCD_I2C
from serial_handler import SerialHandler
from display_manager import DisplayManager

def main():
    """Main execution loop"""
    print("Initializing Pi Pico Stat Display...")
    
    # Initialize I2C
    i2c = machine.I2C(I2C_PORT, scl=machine.Pin(I2C_SCL), sda=machine.Pin(I2C_SDA), freq=400000)
    
    # Initialize LCD displays
    print(f"Scanning I2C devices: {i2c.scan()}")
    lcds = []
    for addr in LCD_ADDRESSES:
        try:
            lcd = LCD_I2C(i2c, addr, 2, 16)  # 2 rows, 16 columns
            lcd.clear()
            lcds.append(lcd)
            print(f"LCD initialized at 0x{addr:02x}")
        except Exception as e:
            print(f"Error initializing LCD at 0x{addr:02x}: {e}")
    
    if len(lcds) < 3:
        print("Warning: Not all LCDs initialized successfully")
    
    # Initialize serial handler
    serial_handler = SerialHandler()
    
    # Initialize display manager
    display_manager = DisplayManager(lcds)
    
    # Display startup message
    if lcds:
        lcds[0].putstr("Starting up...")
        time.sleep(1)
        lcds[0].clear()
    
    # Main loop
    last_update = 0
    while True:
        try:
            # Check for incoming serial data
            data = serial_handler.read_data()
            if data:
                display_manager.update_stats(data)
            
            # Update display every UPDATE_INTERVAL milliseconds
            current_time = time.ticks_ms()
            if time.ticks_diff(current_time, last_update) >= UPDATE_INTERVAL:
                display_manager.display_current_frame()
                last_update = current_time
            
            time.sleep(0.01)  # Small delay to prevent CPU hogging
            
        except Exception as e:
            print(f"Error in main loop: {e}")
            time.sleep(1)

if __name__ == "__main__":
    main()

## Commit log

2026-07-22 Revise BOM with new prices and suppliers
    Updated component prices and sources in bom.csv
    [bom.csv]
2026-08-07 Update bom.csv to include source links
    Added links to component sources in bom.csv.
    [bom.csv]
2026-08-07 Fix formatting of Total line in bom.csv
    [bom.csv]
2026-08-07 Fix link formatting for LCD 1602 I2C backpack
2026-08-31 Update README with assembly instructions and images
    Removed old screenshots and added assembly instructions along with new images.
2026-09-09 Update README to include image instead of diagram
    Removed the component wiring diagram and replaced it with an image.
2026-09-10 Update README with connector details
    Clarified the statement about the hackatime project and connector types.
2026-09-13 Update CAD
    [Back Plate.step, Case.stl, Main Body.step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]
2026-09-13 Update README with printing plans for connectors
    Added a note about planning to print through Hack Club's Print Legion.
2026-09-18 Update component wiring diagram in README
2026-09-21 Update assembly instructions and connector details
    Clarified instructions for connecting screens and updated connector information.
2026-09-21 Revise assembly steps in README
    Updated assembly instructions for clarity.
2026-10-01 Revise README to streamline content and update sections
    Removed sections on monitored stats, screen details, and system features. Updated assembly instructions and changed 'What You Need' to 'BOM'.
2026-10-03 Update BOM and clarify Print Legion costs
    Added Print Legion to the BOM with a cost of $0.00. Clarified the print legion costs in the project description.
2026-10-03 Revise BOM with new components and shipping costs
    Updated component list and prices in BOM.
    [bom.csv]
2026-10-05 Update Print Legion cost and total in bom.csv
    [bom.csv]
2026-10-05 Update Print Legion cost and total in README
